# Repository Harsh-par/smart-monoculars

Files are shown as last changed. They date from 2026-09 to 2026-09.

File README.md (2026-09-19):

# AI-Powered Night Vision Monocular & HUD

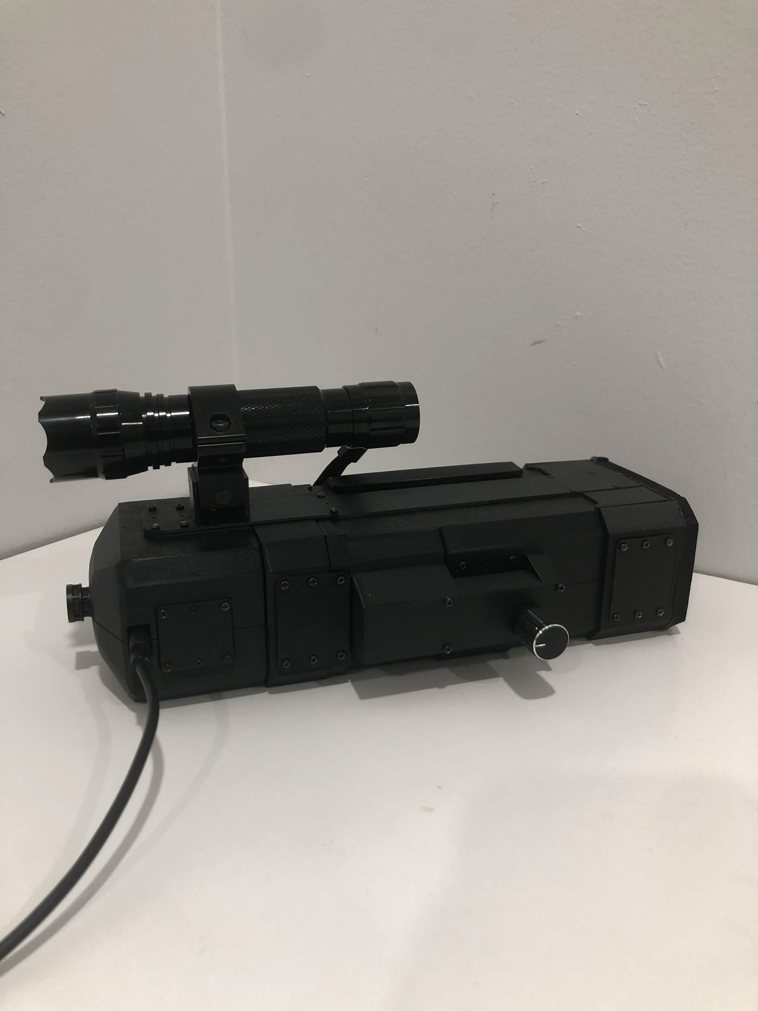
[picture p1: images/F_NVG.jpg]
Night Vision Monoculars


A bare metal C night vision HUD monocular built on the Sipeed Maix Bit (Kendryte K210 dual core 64-bit RISC-V MCU). This system leverages hardware acceleration to distribute computation across **Core 0**, **Core 1**, the dedicated **Knowledge Processing Unit (KPU)**, the hardware **FFT engine**, and the camera’s internal **Image Signal Processor (ISP)**.

---

## How It Works
The Monoculars use active infrared illumination. An external IR flashlight floods the environment with wavelengths invisible to the human eye but can be captured by the camera sensor. This live IR video feed is simultaneously streamed to the HUD for real time viewing and routed to the KPU for hardware accelerated AI object detection.

---

## Gallery

| | |
| :---: | :---: |
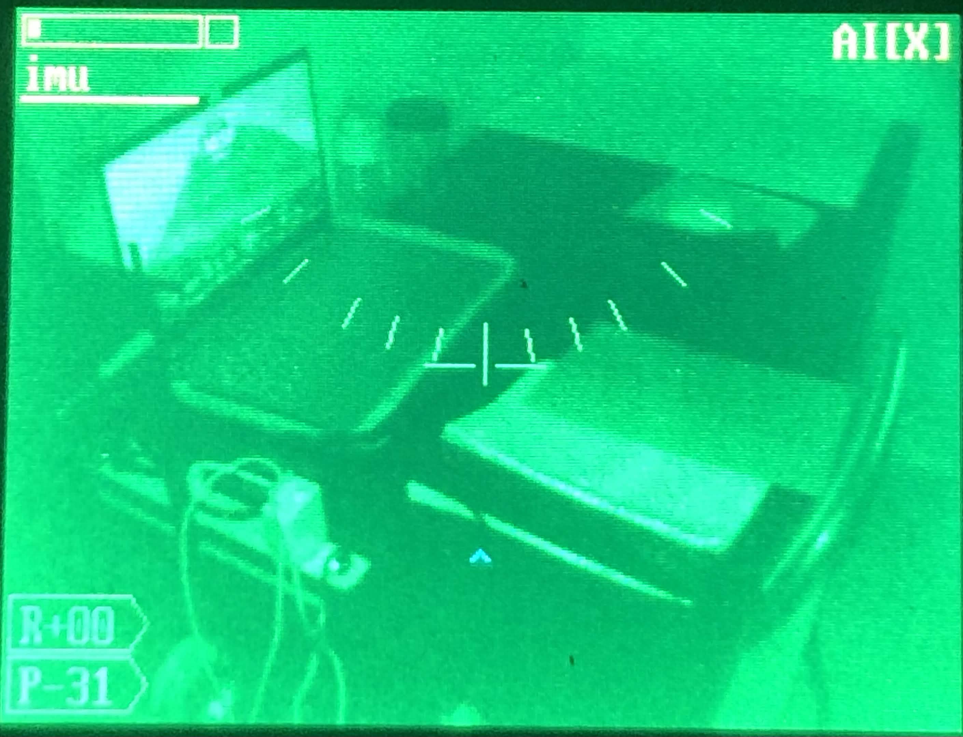
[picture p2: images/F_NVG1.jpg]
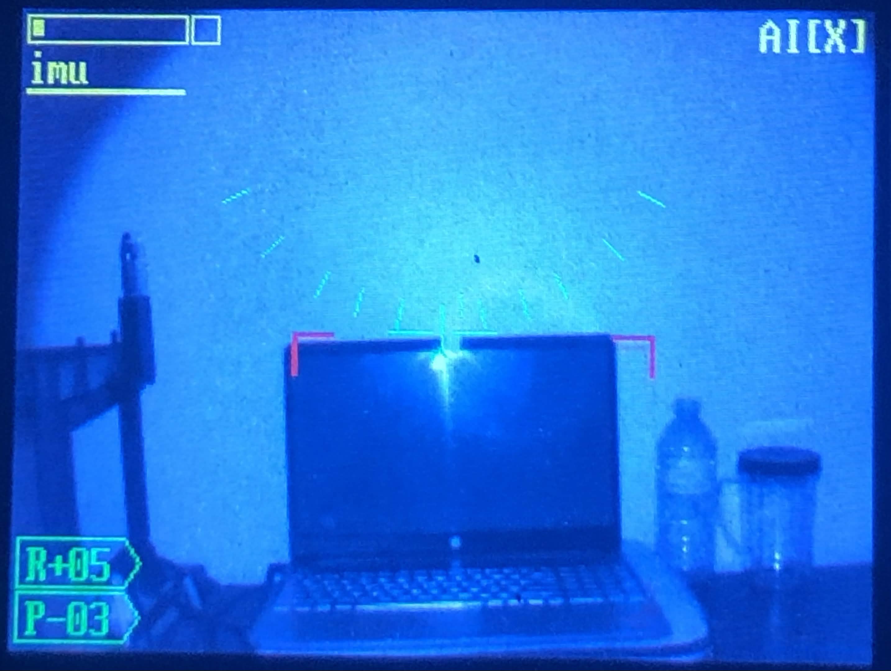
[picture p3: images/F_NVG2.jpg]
|  |  |
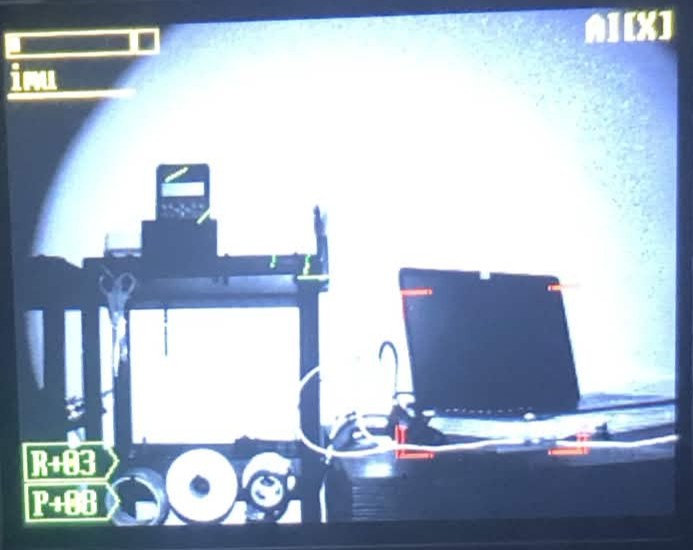
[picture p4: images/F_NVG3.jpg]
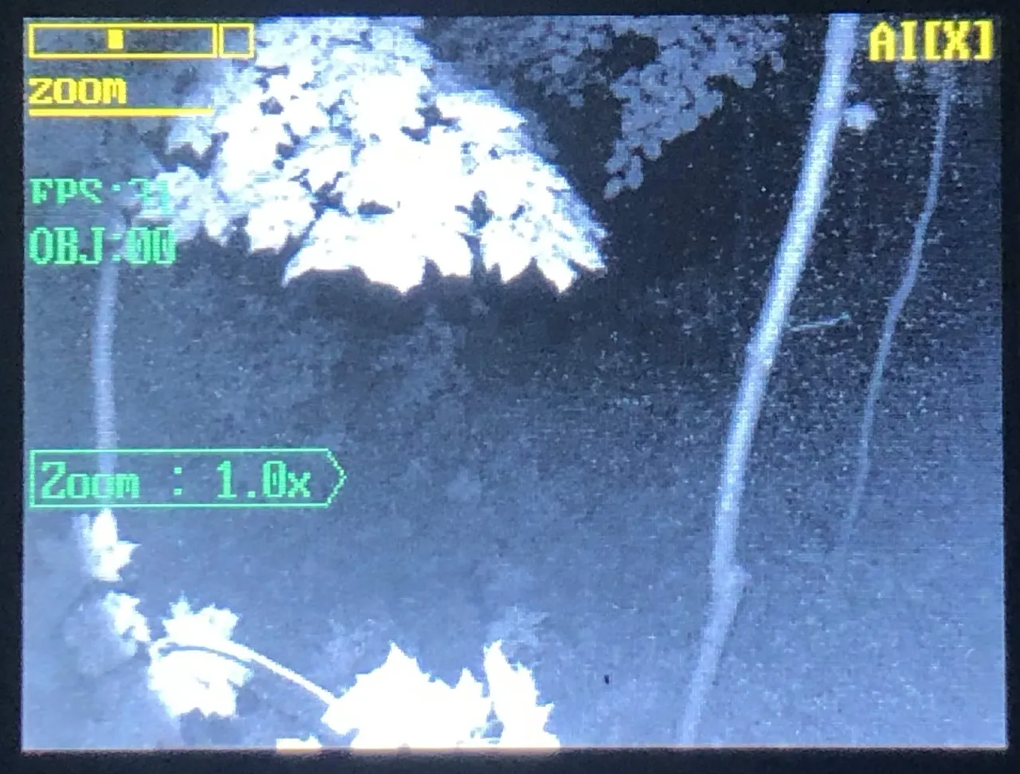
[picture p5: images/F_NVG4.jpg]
|  |  |

---

## Performance Metrics
By offloading heavy computations to dedicated hardware blocks and separating core tasks, the system maintains high frame rates for a fluid HUD experience:

* **~31 FPS** with real time AI object detection enabled (KPU active).
* **~48 FPS** with AI detection disabled (KPU idle).

---

## System Architecture
To achieve low latency without screen tearing, processing is distributed across specialized hardware accelerators operating in parallel:

1. OV5642 Camera ISP & DVP DMA Transfer
Image manipulation, digital zoom, color shifts and visual filters are offloaded directly to the camera's onboard Image Signal Processor (ISP) via I2C/SCCB registers. This saves CPU cycles. The processed video stream is pushed continuously into SRAM using the Digital Video Port (DVP) via Direct Memory Access (DMA).

2. Non Cached Memory Allocation
To speed up data sharing between the display, camera, CPU and KPU, DMA buffer addresses are adjusted by subtracting NON_CACHED_MEMORY_OFFSET. This maps memory directly into non cached physical SRAM (0xA0000000). It enables direct memory access between the camera DVP, AI engine and display buffer without CPU overhead.

3. KPU (Knowledge Processing Unit)
The KPU acts as an independent hardware accelerator for neural networks. It operates in parallel to the main CPU cores. It reads raw frame buffers directly from non cached memory via DMA, computes object detection in hardware, and writes bounding box coordinates and confidence scores back to memory.

4. Core 0 (Display/Camera)
Core 0 serves as the primary display and capture host. It manages DVP capture initialization and handles ISP register controls. Once a frame is captured and the KPU finishes inference, Core 0 reads the bounding box coordinates. It then draws the visual HUD elements and detection boxes onto the display buffer and sends the final frame to the ST7789 LCD via SPI.

5. Core 1 (Sensor/Audio/Telemetry)
Core 1 runs concurrently and is dedicated entirely to background telemetry and user input. It polls the MPU6050 6 axis IMU over I2C to calculate pitch and roll vectors for the artificial horizon. It also samples audio over I2S DMA into the hardware FFT accelerator for real time frequency analysis and decodes rotary encoder interrupts for HUD navigation.

---

## Hardware Specifications
| Component | Interface | K210 Function / Pins |
| :--- | :--- | :--- |
| **OV5642 Camera** | DVP | PCLK, XCLK, HSYNC, VSYNC, SCCB (I2C) |
| **ST7789 LCD** | SPI | CS, DC, WR, SCLK, Data Pins |
| **MPU6050 IMU** | I2C | SDA, SCL |
| **I2S Microphone** | I2S | WS, SCK, SD |
| **Rotary Encoder** | GPIO | Phase A, Phase B, Push Switch |

---

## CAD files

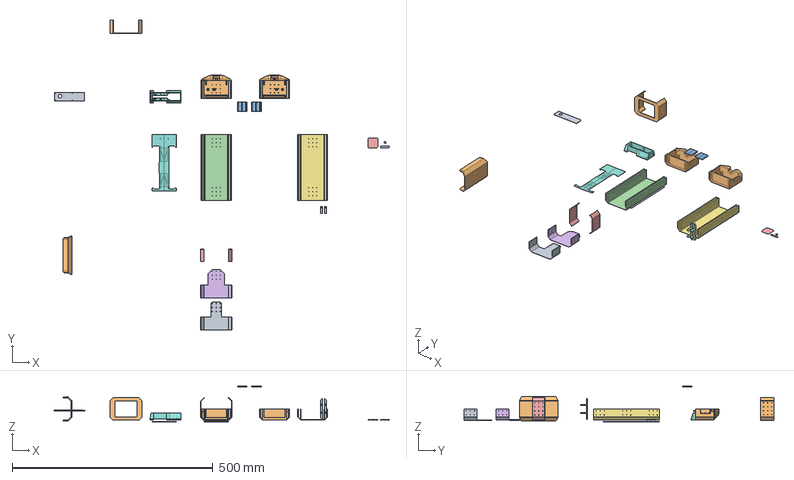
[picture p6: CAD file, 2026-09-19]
model/NightVisionGoggles.step
834.5 x 772.0 x 89.5 mm

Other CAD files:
model/NightVisionGoggles.stl

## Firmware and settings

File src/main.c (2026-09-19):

#include <stdio.h>

#include "sysctl.h"
#include "dmac.h"
#include "plic.h"
#include "dvp.h"
#include "bsp.h"

#include "configuration.h"
#include "constant.h"
#include "kpu_ai.h"
#include "audio.h"
#include "system.h"
#include "gui.h"
#include "mpu6050.h"
#include "st7789.h"
#include "ov5642.h"
#include "rotary_encoder.h"
#include "time_stamp.h"

int main_core1(void* parameter);

volatile uint8_t frame_count_core0 = 0;
volatile uint8_t frame_count_core1 = 0;

volatile uint8_t fps_count_core0 = 0;
volatile uint8_t fps_count_core1 = 0;

volatile bool run_ai_model = true;

volatile obj_info_t obj_info;

int main(void)
{
    uint32_t non_cached_camera_buffer = (uint32_t)camera_buffer - NON_CACHED_MEMORY_OFFSET;
    uint32_t non_cached_ai_buffer     = (uint32_t)ai_buffer     - NON_CACHED_MEMORY_OFFSET;

    system_init();
    ov5642_init((uint8_t*)non_cached_ai_buffer); 
    st7789_init(&st7789, (uint16_t*)non_cached_camera_buffer, LCD_WIDTH, LCD_HEIGHT); 
    kpu_ai_init();
    mpu6050_init(&mpu6050, IMU_CLK_SPEED, IMU_PIN_SDA, IMU_PIN_SCL);
    rotary_encoder_init();

    register_core1(main_core1, NULL);

    while(true)
    {
        if(ov5642_check_frame_ready())
        {
            ov5642_clear_frame_ready(); 

            if(run_ai_model)
            {
                kpu_ai_run_inference();
                kpu_ai_process_results(&obj_info);
                kpu_ai_draw_bounding_box(&st7789, &obj_info, ST7789_RED);
            }
    
            st7789_set_window(&st7789, 0, 0, (st7789.width - 1), (st7789.height - 1));
            st7789_fill_screen(&st7789);
            
            frame_count_core0 = frame_count_core0 + 1;
        }
    }

    return 0;
}

int main_core1(void *parameter) 
{
    uint64_t current_time_us = sysctl_get_time_us();

    time_stamp_t time_stamp_core1;
    time_stamp_t time_stamp_frame;
    time_stamp_t time_stamp_encoder_knob;
    time_stamp_t time_stamp_encoder_button;
    time_stamp_t time_stamp_overlay;

    time_stamp_init(&time_stamp_core1,          current_time_us);
    time_stamp_init(&time_stamp_frame,          current_time_us);
    time_stamp_init(&time_stamp_encoder_knob,   current_time_us);
    time_stamp_init(&time_stamp_encoder_button, current_time_us);
    time_stamp_init(&time_stamp_overlay,        current_time_us);

    audio_init();

    uint8_t previous_encoder_layer = ROT_ENC_LAYER_COUNT;

    while(true) 
    {
        current_time_us = sysctl_get_time_us();
        time_stamp_update_delta(&time_stamp_core1, current_time_us);
        
        uint8_t current_encoder_layer = rotary_encoder_get_layer();
        uint8_t current_encoder_state = rotary_encoder_get_state();
        
        if(time_stamp_check_elapsed(&time_stamp_frame, current_time_us, ONE_SECOND_IN_US))
        {
            fps_count_core0 = frame_count_core0;
            fps_count_core1 = frame_count_core1;

            frame_count_core0 = 0;
            frame_count_core1 = 0;
        }        

        if((previous_encoder_layer != current_encoder_layer) && time_stamp_check_elapsed(&time_stamp_encoder_knob, current_time_us, ROT_ENC_DEBOUNCE_US))
        {       
            previous_encoder_layer = current_encoder_layer;
        }

        switch(current_encoder_layer)
        {
            case GUI_IMU: 
            {
                if(current_encoder_state && time_stamp_check_elapsed(&time_stamp_encoder_button, current_time_us, ROT_ENC_BTN_DEBOUNCE_US))
                { 
                    run_ai_model = !run_ai_model;
                }

                mpu6050_read(&mpu6050);
                mpu6050_compute(&mpu6050);
                mpu6050_filter_pitch(&mpu6050, time_stamp_core1.delta_s);
                mpu6050_filter_roll(&mpu6050,  time_stamp_core1.delta_s);

                gui_display_hud_imu(&st7789, &mpu6050, ST7789_GREEN2, ST7789_GREEN);
                break;
            }
            case GUI_AUDIO: 
            {
                if(current_encoder_state && time_stamp_check_elapsed(&time_stamp_encoder_button, current_time_us, ROT_ENC_BTN_DEBOUNCE_US))
                { 
                    run_ai_model = !run_ai_model;
                }

                audio_read();

                gui_display_hud_audio(&st7789, ST7789_GREEN2);
                break;
            }
            case GUI_DATA:
            {
                if(current_encoder_state && time_stamp_check_elapsed(&time_stamp_encoder_button, current_time_us, ROT_ENC_BTN_DEBOUNCE_US))
                { 
                    run_ai_model = !run_ai_model;
                }

                if(!run_ai_model) obj_info.obj_number = 0;

                gui_display_hud_data(&st7789, fps_count_core0, fps_count_core1, obj_info.obj_number, ST7789_GREEN2);
                break;
            }
            case GUI_FILTER: 
            {   
                static uint16_t current_filter  = FILTER_NONE;
                static char *text_buffer_filter = "Filter : None";

                if(current_encoder_state && time_stamp_check_elapsed(&time_stamp_encoder_button, current_time_us, ROT_ENC_BTN_DEBOUNCE_US))
                {
                    gui_display_hud_filters(&st7789, &current_filter, &text_buffer_filter);
                }
                
                gui_draw_text_tag(&st7789, 2, 142, text_buffer_filter, ST7789_GREEN2);
                gui_display_fps(&st7789, fps_count_core0, obj_info.obj_number, ST7789_GREEN2);
                break;
            }
            case GUI_ZOOM:
            {
                static uint16_t current_zoom  = ZOOM_1p0x;
                static char *text_buffer_zoom = "Zoom : 1.0x";

                if(current_encoder_state && time_stamp_check_elapsed(&time_stamp_encoder_button, current_time_us, ROT_ENC_BTN_DEBOUNCE_US))
                {
                    gui_display_hud_zoom(&st7789, &current_zoom, &text_buffer_zoom);
                }

                gui_draw_text_tag(&st7789, 2, 142, text_buffer_zoom, ST7789_GREEN2);
                gui_display_fps(&st7789, fps_count_core0, obj_info.obj_number, ST7789_GREEN2);
                break;
            }
        }

        gui_display_overlay(&st7789, current_encoder_state, current_encoder_layer, run_ai_model, ST7789_YELLOW, ST7789_BLACK);
     
        frame_count_core1 = frame_count_core1 + 1;
    }

    return 0;
}

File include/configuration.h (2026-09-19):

#ifndef CONFIGURATION_H
#define CONFIGURATION_H

#define NVG_LEFT_SCREEN  
//#define NVG_RIGHT_SCREEN

#define SYSTEM_PLL0_FREQ 800000000UL
#define SYSTEM_PLL1_FREQ 400000000UL
#define SYSTEM_PLL2_FREQ 45158400UL

#define IMU_CLK_SPEED (400 * 1000)

#define IMU_PIN_SDA   34
#define IMU_PIN_SCL   35

#define LCD_CLK_SPEED (22 * 1000 * 1000)

#define LCD_PIN_CLK   39
#define LCD_PIN_CS    36
#define LCD_PIN_RST   37
#define LCD_PIN_DC    38
#define LCD_PIN_BLK   17

#define LCD_GPIO_DC   0
#define LCD_GPIO_RST  1
#define LCD_GPIO_BLK  3

#define CAM_PIN_SDA   40
#define CAM_PIN_SCL   41
#define CAM_PIN_RST   42
#define CAM_PIN_VSYNC 43  
#define CAM_PIN_PWDN  44  
#define CAM_PIN_HREF  45  
#define CAM_PIN_XCLK  46  
#define CAM_PIN_PCLK  47

#define CAM_GPIO_RST  4
#define CAM_GPIO_PWDN 5

#define MIC_PIN_BCLK  18  
#define MIC_PIN_WS    19 
#define MIC_PIN_DAT   20 

#define ROT_GPIO_BTN  6
#define ROT_GPIO_ENCA 7
#define ROT_GPIO_ENCB 8

#define ROT_PIN_BTN   22
#define ROT_PIN_ENCA  23
#define ROT_PIN_ENCB  24

#define DVP_OUT_KPU   0
#define DVP_OUT_LCD   1

#endif

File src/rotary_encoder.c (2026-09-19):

#include "rotary_encoder.h"

static volatile uint16_t encoder_layer = 0;

static volatile uint64_t previous_increment_us = 0; 
static volatile uint64_t previous_decrement_us = 0; 

static int rotary_encoder_handler(void *parameter)
{
    static const int8_t encoder_state_table[] = {0,-1,1,0,1,0,0,-1,-1,0,0,1,0,1,-1,0};

    uint64_t current_time_us = sysctl_get_time_us();
  
    static uint8_t previous_states = 0b00000011;  
    static int8_t encoder_value = 0;  

    previous_states = previous_states << 2; 

    if(gpiohs_get_pin(ROT_GPIO_ENCA)) previous_states |= 0b00000010; 
    if(gpiohs_get_pin(ROT_GPIO_ENCB)) previous_states |= 0b00000001; 
  
    encoder_value = encoder_value + encoder_state_table[(previous_states & 0b00001111)];

    if(encoder_value > 3)
    {      
        int8_t encoder_step = 1;

        if(current_time_us - previous_increment_us < ROT_ENC_DEBOUNCE_US)
        {
            encoder_step = ROT_ENC_STEP_SIZE * encoder_step; 
        }

        previous_increment_us = current_time_us;
        encoder_layer = (encoder_layer + encoder_step + ROT_ENC_LAYER_COUNT) % ROT_ENC_LAYER_COUNT;            
        encoder_value = 0;
    }
    else if(encoder_value < -3)
    {        
        int8_t encoder_step = -1;

        if(current_time_us - previous_decrement_us < ROT_ENC_DEBOUNCE_US)
        {
            encoder_step = ROT_ENC_STEP_SIZE * encoder_step; 
        }

        previous_decrement_us = current_time_us;
        encoder_layer = (encoder_layer + encoder_step + ROT_ENC_LAYER_COUNT) % ROT_ENC_LAYER_COUNT;            
        encoder_value = 0;
    }

    return 0; 
}

void rotary_encoder_init(void)
{
    fpioa_set_function(ROT_PIN_BTN,  FUNC_GPIOHS6);
    fpioa_set_function(ROT_PIN_ENCA, FUNC_GPIOHS7);
    fpioa_set_function(ROT_PIN_ENCB, FUNC_GPIOHS8);

    gpiohs_set_drive_mode(ROT_GPIO_BTN,  GPIO_DM_INPUT_PULL_UP);
    gpiohs_set_drive_mode(ROT_GPIO_ENCA, GPIO_DM_INPUT_PULL_UP);
    gpiohs_set_drive_mode(ROT_GPIO_ENCB, GPIO_DM_INPUT_PULL_UP);

    gpiohs_set_pin_edge(ROT_GPIO_ENCA, GPIO_PE_BOTH);
    gpiohs_set_pin_edge(ROT_GPIO_ENCB, GPIO_PE_BOTH);

    gpiohs_irq_register(ROT_GPIO_ENCA, 1, rotary_encoder_handler, NULL);
    gpiohs_irq_register(ROT_GPIO_ENCB, 1, rotary_encoder_handler, NULL);
}

uint16_t rotary_encoder_get_layer(void)
{
    return encoder_layer;
}

uint8_t rotary_encoder_get_state(void)
{
    return !gpiohs_get_pin(ROT_GPIO_BTN);
}

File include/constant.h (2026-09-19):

#ifndef CONSTANT_H
#define CONSTANT_H

#define NON_CACHED_MEMORY_OFFSET 0x40000000

#define LCD_WIDTH  320
#define LCD_HEIGHT 240

#define LCD_ALIGNMENT 64

#define MICROSECOND_TO_SECOND 0.000001f
#define ONE_SECOND_IN_US      1000000ULL

#define RGB_CHANNELS 3

#define GPIO_HIGH 1
#define GPIO_LOW  0

#define MAX_OBJECT_DETECTIONS 50

#define RADIAN_TO_DEGREE 57.29577951f

#endif

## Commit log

2026-09-19 Initial commit: firmware and drivers for ov5642/st7789/mpu6050
    [configuration.h]
2026-09-19 Images and .step/.stl
    [NightVisionGoggles.step, NightVisionGoggles.stl]
